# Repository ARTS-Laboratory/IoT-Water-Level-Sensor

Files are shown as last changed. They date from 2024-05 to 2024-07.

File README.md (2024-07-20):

# IoT Water Level Sensor

This is a water height sensor developed by the ARTS-Lab at the University of South Carolina in conjunction with the South Carolina Department of Environmental Services (SC DES) Dam Safety Program. The purpose of this sensor is to provide a low-cost, open-source alternative to traditional gaging equipment. 

<p align="center">

</p>
<p align="center">
Sensor deployed above inlet to Lake Wallace in Bennetsville, SC.
</p>

<p align="center">
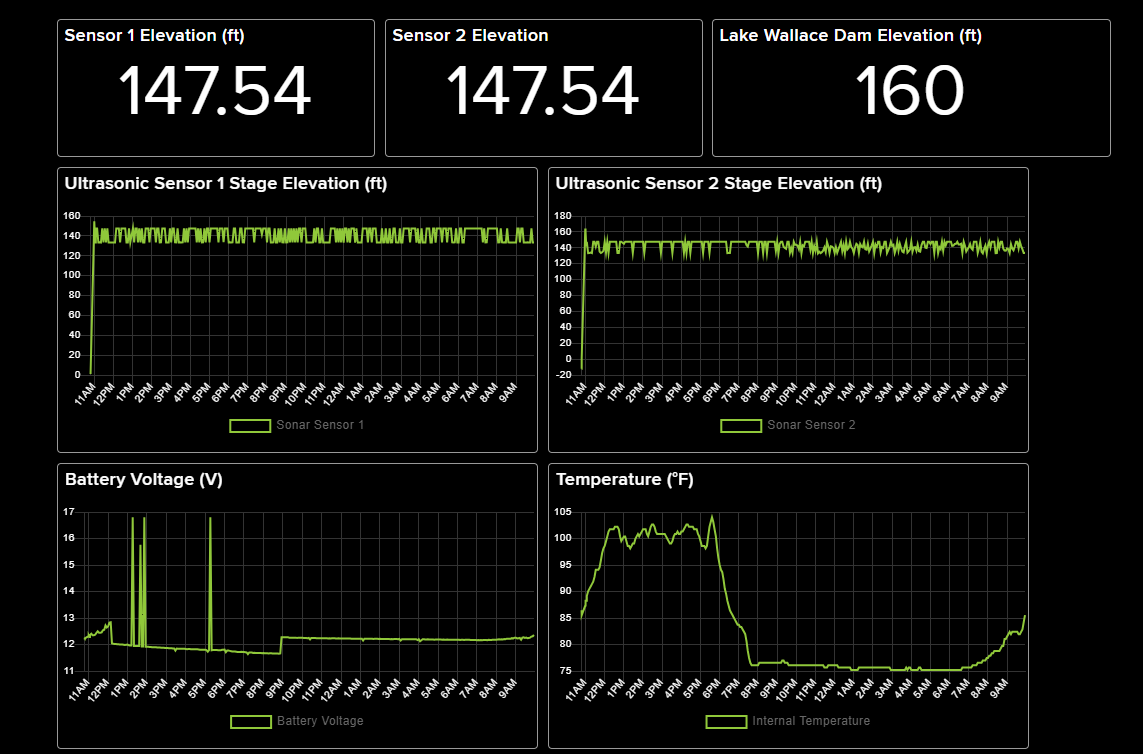
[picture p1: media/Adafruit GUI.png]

</p>
<p align="center">
The online GUI using Adafruit that displays water elevation in real time.
</p>

## Features
### Water Elevation Measurement
The sensor package uses two ultrasonic sensors to measurement the height of water in a reservoir, lake, or pond. These sensors are low cost, but are accurate to +/- 1 inch within a range of 18 ft.
<p align="center">

</p>
<p align="center">
The low cost, JSN-SR04T ultrasonic sensor used with Arduinos.
</p>

### Internet Connectivity
Our package can connect to the Adafruit online server. A free account can be made with them to host data online, and a small subscription fee can upgrade the service for more data storage.
</p>
This device can connect to Internet via cellular or Wifi.
<p align="left">

<align="right">

</p>
On the left, the SIM7000 cellular shield. On the right, the WINC1500 Wifi shield.
</p>

### Long Term Data Storage
Because the online server only saves data for 60 days, to ensure that all data is recorded for future use, we use an SD card and Real Time clock with this sensor package to save all data with a timestamp in a .CSV format. 

## System Development
Contains the hardware and software developed for the project. Use this folder to create and troubleshoot a sensor.

## Licensing and Citation

This work is licensed under a Creative Commons Attribution-ShareAlike 4.0 International License [cc-by-sa 4.0].



Cite this as: 

@Misc{ARTSLabIotWaterLevel,    
  author = {ARTS-Lab},  
  howpublished = {GitHub},  
  title  = {IoT Water Level Sensor},   
  groups = {ARTS-Lab},    
  url    = {https://github.com/ARTS-Laboratory/IoT-Water-Level-Sensor},   
}

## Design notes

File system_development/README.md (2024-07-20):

# Systems Variations  
The IOT water height sensor comes in two main categories: Cellular and Wifi.
<p>
Select whichever method you would like to use to connect your water height sensor to the Internet. Each varation comes with the complete files needed to find parts, assemble the package, and program the Arduino.
</p>

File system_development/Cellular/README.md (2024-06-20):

# Celluar Versions

## v0.1
Legacy version (2022 - 2023) 

## v0.2
Current version (2024 - )

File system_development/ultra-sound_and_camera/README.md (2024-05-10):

# Ultra-sound and Camera

v0.1
* list items that make this version special
* list items that make this version special
* list items that make this version special

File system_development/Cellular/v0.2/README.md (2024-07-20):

# Celluar V0.2

### Arduino Code
This folder contains all of the Arduino code used in this sensor project, including special custom formatted libraries that you will have to install in order to make the Arduino code work properly on your hardware.

### Custom PCB's
This folder contains the KiCad files used to create the custom data logging PCB and power management PCB.

### Parts List
A detailed parts list with part numbers and ordering information. This list gives the location and price of where we ordered every part to assemble both the package and the individual PCB's.
The parts used in the PCB's have their identification number from the schematics included so that you will be able to see where each part goes when assembling the PCB's.

# Important Information:

### Botletics SIM7000 Shield

This sensor package uses a Botletics SIM7000 shield to connect to the Internet over the cellular network.
The wiki for this board is found [here](https://www.botletics.com/products/sim7000-shield) for more information.
Here is a tutorial for how to set up and use the board: [Instructables](https://www.instructables.com/LTE-NB-IoT-Shield-for-Arduino/) *Note that we do not use a separate 3.7V battery to power our sensor package.

### Hologram SIM card

To connect to the Internet over the cell network, you will need to have a SIM card. You can buy a SIM card from [Hologram](https://www.hologram.io/).
You will need to register with Hologram, purchase a SIM card and a data plan, and then work with your SIM card over the Hologram site.
Our SIM card is this [IOT card](https://store.hologram.io/products/single-core-global-euicc-iot-sim-card). 

### Adafruit IO

We use the Adafruit IO server to monitor our sensor package over the Internet in real time. You will need to create an account with Adafruit, however it is free.
To learn how to sign up for the Adafruit IO server, use this [tutorial](https://learn.adafruit.com/welcome-to-adafruit-io).
You will also need to learn how to use [feeds](https://learn.adafruit.com/adafruit-io-basics-feeds) and [dashboards](https://learn.adafruit.com/adafruit-io-basics-dashboards).

### PCB's

To use this sensor, you will have to assemble custom PCB's. The PCB's were designed using the [KiCad](https://www.kicad.org/) software, a free-to-use PCB editor. All the schematics can be found in the Datalogging and Power PCB folders under the file name .kicad_sch. The provided parts list references the .kicad_sch files so that you can know how to assemble the PCB on your own. Datasheets for each part can also be found within the .kicad_sch file.
We have ordered PCB's from [OSH Park](https://oshpark.com/) and have liked the results. Simply drag and drop the .kicad_pcb file from the PCB folder into OSH Park to create a PCB!

# Assembly Instructions

### Assemble PCB's

The first step is acquire PCB and solder the components. Refer to the .kicad_sch and .kicad_pcb files in the respective folders for the placement of each component. 
Their locations have been labeled on the PCB's for greater ease.

(Include pictures of before and after)

### Fit Boards

The next step is to put together the Arduino Mega, Botletics SIM7000 shield, and the completed PCB's as shown:

(Include pictures)

### Formatting the Code

To get the CellularCodev0.2 to work with your particular Adafruit account, we will have to format the code a little.

First acquire your username and key from the Adafruit IO website:

<p align="center">
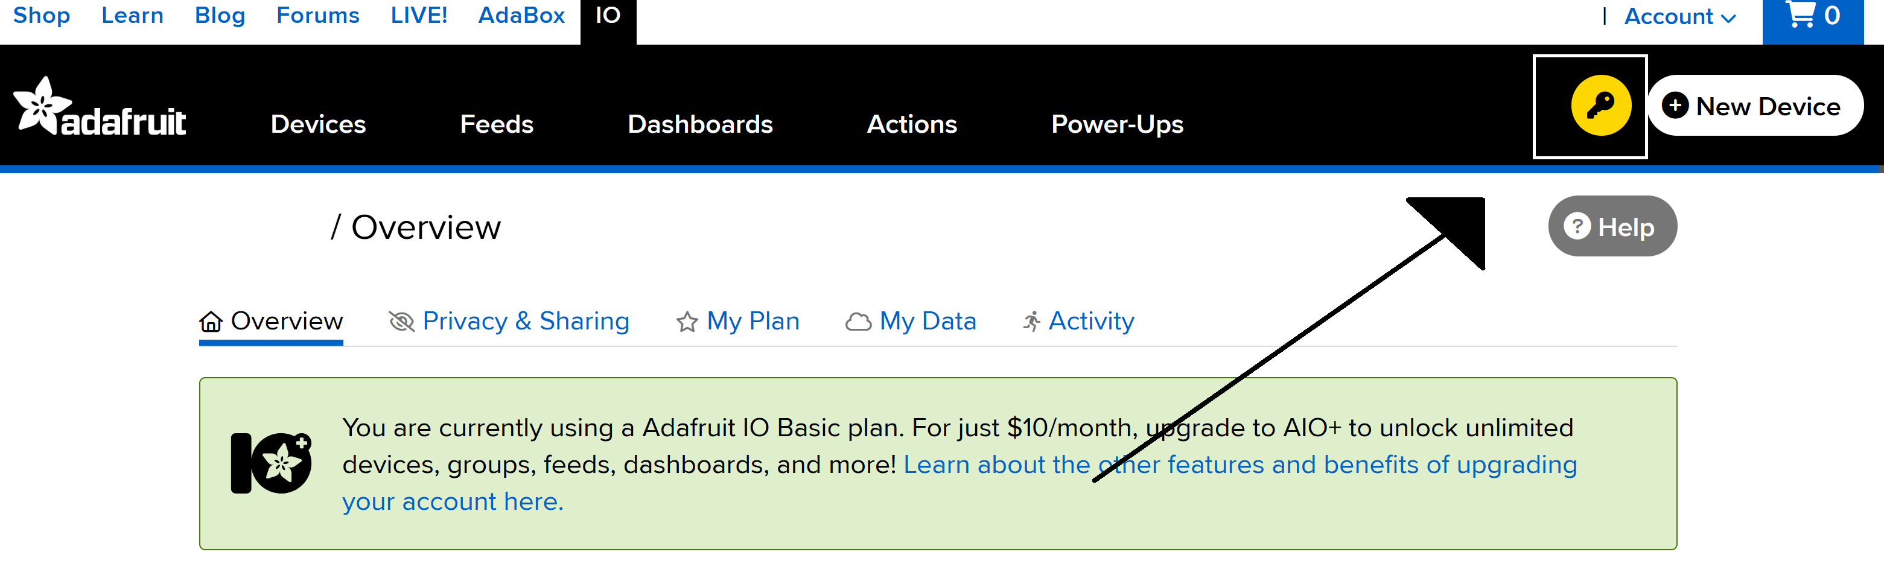
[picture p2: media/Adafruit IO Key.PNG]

</p>

Using your Adafruit username and key, fill in this line in the code:

<p align="center">
<img src="https://github.com/ARTS-Laboratory/IoT-Water-Level-Sensor/blob/main/media/Adafruit%20Arduino%20Key%20Location.PNG" alt="drawing" width=600"/>
</p>

Power your device, turn it on, and start transmitting! All relevant schematics are provided for the PCB's, and the Arduino code is annotated with explanations. Feel free to dig into both to tweak the device to your desire.

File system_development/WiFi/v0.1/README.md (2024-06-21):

# Wifi V0.1

## WifiCode_v0.1
This folder contains all of the Arduino code used in this sensor project.

## Data Collection - Logging PCB
This folder contains the KiCad files used to create the custom data logging PCB

## Power PCB
This folder contains the KiCad files used to create the custom Power supply and monitoring PCB

## Parts List
A detailed parts list with part numbers and ordering information can be found in the Wifi Water Height Sensor
Package Parts List.

# Important Information:

### WINC1500 Shield

This sensor package uses a WINC1500 shield to connect to the Internet over Wifi.
It is produced by Adafruit Industries. Here is a [tutorial](https://learn.adafruit.com/adafruit-winc1500-wifi-shield-for-arduino) by them for how to set up and use the board.
The WINC1500 has an SD card module on it.

### Adafruit IO

We use the Adafruit IO server to monitor our sensor package over the Internet in real time. You will need to create an account with Adafruit, however it is free.
To learn how to sign up for the Adafruit IO server, use this [tutorial](https://learn.adafruit.com/welcome-to-adafruit-io).
You will also need to learn how to use [feeds](https://learn.adafruit.com/adafruit-io-basics-feeds) and [dashboards](https://learn.adafruit.com/adafruit-io-basics-dashboards).

### PCB's

To use this sensor, you will have to assemble custom PCB's. All the schematics can be found in the Datalogging and Power PCB folders and parts list. 
We have ordered PCB's from [OSH Park](https://oshpark.com/) and have liked the results. Simply drag and drop the .kicad_pcb file from the PCB folder into OSH Park to create a PCB!

# Assembly Instructions

### Assemble PCB's

The first step is acquire PCB and solder the components. Refer to the .kicad_sch and .kicad_pcb files in the respective folders for the placement of each component. 
Their locations have been labeled on the PCB's for greater ease.

(Include pictures of before and after)

### Fit Boards

The next step is to put together the Arduino Mega, WINC1500 shield, and the completed PCB's as shown:

(Include pictures)

### Formatting the Code

To get the WifiCode_v0.1 to work with your particular Adafruit account, we will have to format the code a little.

First acquire your username and key from the Adafruit IO website:

<p align="center">

</p>

Using your Wifi Network name and password, fill in these lines in the code:

<p align="center">
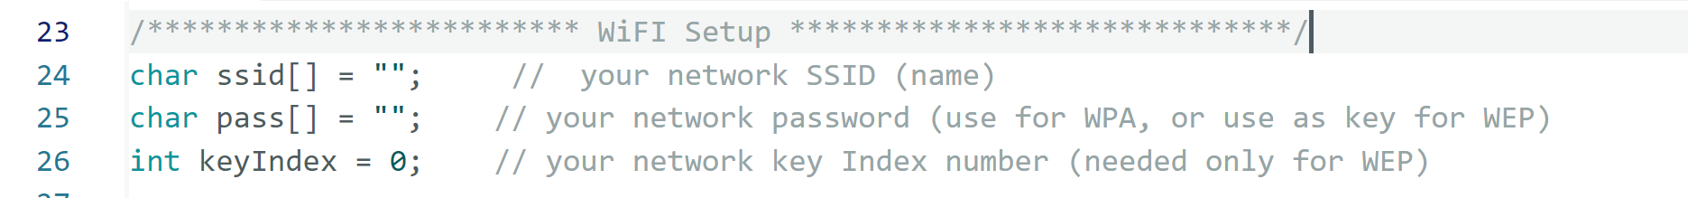
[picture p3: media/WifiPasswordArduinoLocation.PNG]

</p>

Power your device, turn it on, and start transmitting! All relevant schematics are provided for the PCB's, and the Arduino code is annotated with explanations. Feel free to dig into both to tweak the device to your desire.

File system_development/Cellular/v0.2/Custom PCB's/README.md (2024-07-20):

# PCB Files
The cellular board requires two custom PCB's, one for power management and one for data collection. Both are designed and edited using the Kicad software.

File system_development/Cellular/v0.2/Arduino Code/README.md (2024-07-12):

# Arduino Code

## Sensor Code
The INO file is the Arduino code which can be uploaded to an Arduino Mega. Remember to include
the Adafruit user name and AIO key so that it will connect to the right server.

## Special Libraries
The code will not work without special Arduino libraries that have been altered 
and need to manually installed in the "Arduino libraries" folder, overwriting the existing libraries if they
were already installed. All files are tested and are mutually compatible. We have found compatibility
issues with other versions of these libraries, so it is important that all are manually installed
in the Arduino libraries folder.

## Auxillary Code
This contains three helpful Arduino codes. One sets the time on an RTC in order to calibrate it. 
The other is a demo code which can also be found in the Botletics folder in the Special Arduino Libraries folder.
The LTE Demo is useful to troubleshoot connectivity issues with the SIM card. The last is an I2C address finder which
can be used to find the I2C address of the INA219 current measuring chip.

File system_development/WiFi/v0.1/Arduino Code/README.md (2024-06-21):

# Arduino Code

### Sensor Code

The INO file is the Arduino code which can be uploaded to an Arduino Mega. Remember to include
the Adafruit user name and AIO key so that it will connect to the right server.

The libraries used with the Wifi sensor package are standard and can be downloaded unto your computer using the 
Arduino software

### Auxillary Code

This contains two helpful Arduino codes, one to the set the time on an RTC in order to calibrate it. 
The other is a demo code which can also be found in the Wifi101 folder in the Examples tab in the Arduino software
after the Wifi101 library has been installed. This will help to troubleshoot connectivity issues.

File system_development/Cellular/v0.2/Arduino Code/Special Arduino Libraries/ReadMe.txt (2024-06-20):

# Special Libraries

## Adafruit_FONA / Adafruit_MQTT_Library / BotleticsSIM7000
The libraries for the cellular model are hodge-podge and subject to problems. The original Adafruit Fona library has to be overwritten
by the special Botletics Adafruit Fona Library that connects code for use with LTE. The Sim7000 works off of LTE data
and the original Adafruit Fona Library does not contain LTE connection code. Also, the line "#define SSL_FONA 1" in the
.h code in the Fona Library needs to be changed to "#define SSL_FONA 0" for the code to work. Copies of working Arduino libraries are contained
in this folder in case an automatic update changes the Arduino libraries and prevents the module from working.

## All Others
The other libraries are more standard and are included only for convenience. They are needed to use some of the hardware included in the sensor package. They can be installed from the Arduino software
and are included here if you would like to manually install them.

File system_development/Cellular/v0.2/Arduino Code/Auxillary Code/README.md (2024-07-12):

# Auxillary Code

## LTE_Demo
This was developed by Botletics and can be used with the Botletics board to diagnose connectivity issues with the Botletics shield or SIM card

## RTC_Set_Time
This code sets the Real Time Clock to the current time.

##I2C Address Finder
Gives the I2C address of the INA219 chip, usually 0x4X, which can change depending on the type of chip used.
The right I2C address has to be programmed in the Cellular Code for the INA219 chip to work correctly.

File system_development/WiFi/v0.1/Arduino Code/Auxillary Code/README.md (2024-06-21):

# Auxillary Code

### Connect with WPa

This is used with the Wifi shield to test a Wifi connect with WPA (typical) credentials. Use it to see
whether you Wifi connection and signal strength is good enough to transmit data.

### RTC_Set_Time

This code sets the Real Time Clock to the current time.

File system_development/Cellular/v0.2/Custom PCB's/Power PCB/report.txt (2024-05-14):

Plotted to 'C:\Users\User\Documents\GitHub\IoT-Water-Level-Sensor\system_development\Cellular\v0.2\Power PCB\Power PCB-F_Cu.gbr'.
Plotted to 'C:\Users\User\Documents\GitHub\IoT-Water-Level-Sensor\system_development\Cellular\v0.2\Power PCB\Power PCB-B_Cu.gbr'.
Plotted to 'C:\Users\User\Documents\GitHub\IoT-Water-Level-Sensor\system_development\Cellular\v0.2\Power PCB\Power PCB-F_Paste.gbr'.
Plotted to 'C:\Users\User\Documents\GitHub\IoT-Water-Level-Sensor\system_development\Cellular\v0.2\Power PCB\Power PCB-B_Paste.gbr'.
Plotted to 'C:\Users\User\Documents\GitHub\IoT-Water-Level-Sensor\system_development\Cellular\v0.2\Power PCB\Power PCB-F_Silkscreen.gbr'.
Plotted to 'C:\Users\User\Documents\GitHub\IoT-Water-Level-Sensor\system_development\Cellular\v0.2\Power PCB\Power PCB-B_Silkscreen.gbr'.
Plotted to 'C:\Users\User\Documents\GitHub\IoT-Water-Level-Sensor\system_development\Cellular\v0.2\Power PCB\Power PCB-F_Mask.gbr'.
Plotted to 'C:\Users\User\Documents\GitHub\IoT-Water-Level-Sensor\system_development\Cellular\v0.2\Power PCB\Power PCB-B_Mask.gbr'.
Plotted to 'C:\Users\User\Documents\GitHub\IoT-Water-Level-Sensor\system_development\Cellular\v0.2\Power PCB\Power PCB-Edge_Cuts.gbr'.
Created Gerber job file 'C:\Users\User\Documents\GitHub\IoT-Water-Level-Sensor\system_development\Cellular\v0.2\Power PCB\Power PCB-job.gbrjob'.
Info: Done.

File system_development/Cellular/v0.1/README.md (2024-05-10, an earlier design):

# Cellular v0.1

This is an Arduino Mega-based stage sensor developed by interns at the South Carolina Department of Health and Environmental Control (SC DHEC) Dam Safety Program. The purpose of this sensor is to provide a low-cost, open-source alternative to traditional gaging equipment. Both an ultrasonic sensor and a pressure transducer are used to measure the stage, and all data is sent via the Hologram cellular network to a graphic user interface (GUI) hosted on Adafruit IO. *Note: this repository was formerly named "DHEC-Stage-Sensor".

<p align="center">
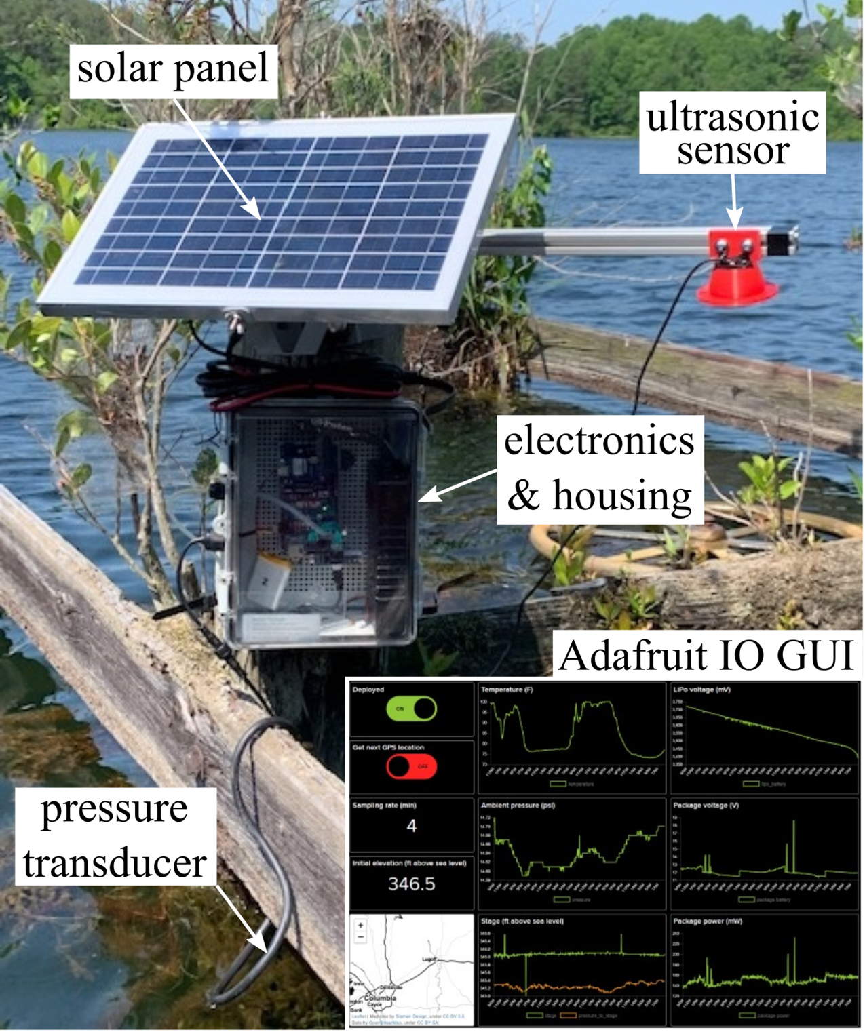
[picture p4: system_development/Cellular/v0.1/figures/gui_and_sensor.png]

</p>
<p align="center">
Figure 1: Sensor deployed on the primary spillway of a dam transmitting data to the GUI.
</p>

## characteristic data
contains validation data for the sensor, as well as test data for filtering, pressure transducer calibration

## code
contains all the Arduino codes for the sensor

## EDA
contains all electronic design automation (EDA) files for the custom data logging and power PCBs

## field tests
contains data for all field tests performed with the sensor package, as well as Python scripts for visualizing data

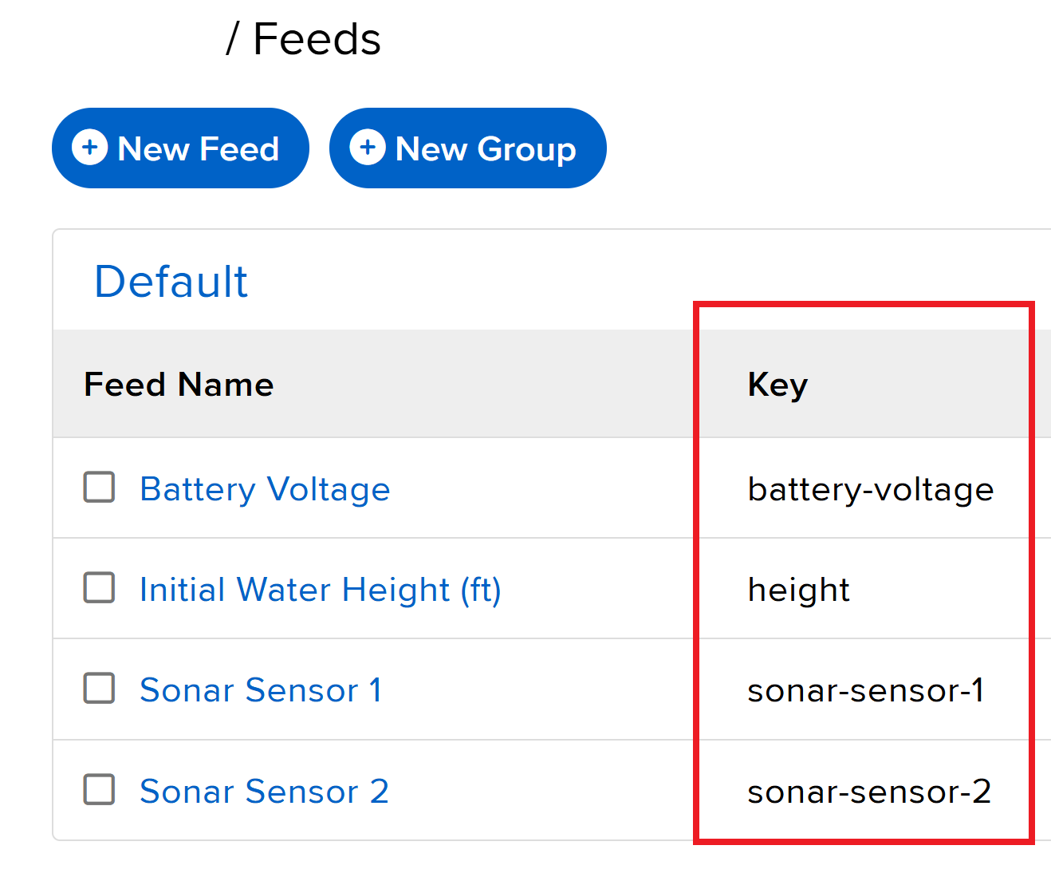
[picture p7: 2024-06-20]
media/Adafruit IO Feed Names.PNG

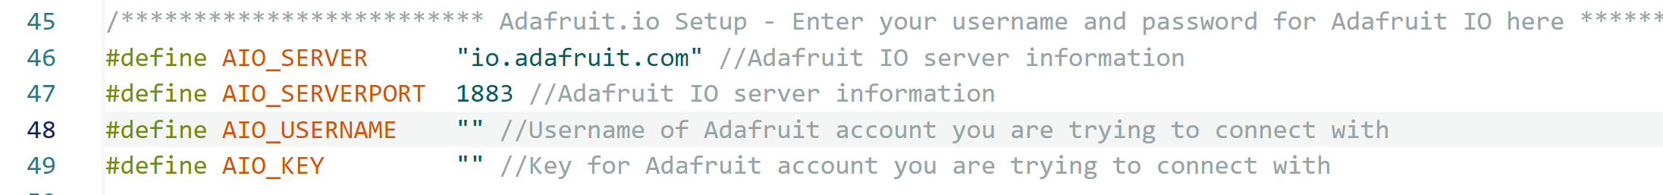
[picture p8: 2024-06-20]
media/Adafruit Arduino Key Location.PNG

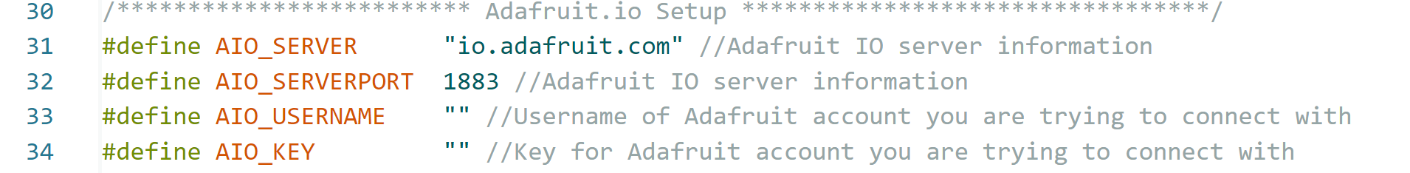
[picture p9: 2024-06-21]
media/WifiArduinoKey Location.PNG

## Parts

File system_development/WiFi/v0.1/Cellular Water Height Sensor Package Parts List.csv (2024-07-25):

Material Ordering List
Part Name
Power Board PCBv0.2 | Manufacturer Part # | Digikey Part # | Supplier | Code on Schematic | Price per unit (5/14/2024)
Barrell Jack | PJ-102B | CP-102B-ND | CUI Devices | J1 | $0.65
Slide Switch | AS11AP | 360-3719-ND | NKK Switches | SW1 | $4.07
Diode SMD | DDZ16-7 | 31-DDZ16-7TR-ND | Diodes Incorporated | D1 | $0.25
Resistor SMD | RL1206FR-070R1L | 311-0.1LWTR-ND | YAGEO | R1 | $0.43
Capacitor SMD | KGM31BR71H104KT | 478-KGM31BR71H104KTTR-ND | KYOCERA AVX | C1 / C2 | $0.18
Current Measuring Chip | INA219AIDR | 296-23978-2-ND | Texas Instruments | U2 | $2.16
Resistor SMD | RC1206FR-074K7L | 311-4.70KFRTR-ND | YAGEO | R3 / R4 | $0.10
5V Linear Regulator | LF50CDT-TR | 497-1534-2-ND | STMicroelectronics | U1 | $0.99
Power Board PCB | Custom | Custom | OSH Park | N/A
Datalogging Boardv0.21 | Manufacturer Part # | Digikey Part # | Supplier | Code on Schematic
3.3 V Linear Regulator | UA78M33IKVURG3 | 296-41035-2-ND | Texas Instruments | U1 | $0.83
Capacitor SMD | CL31B104KBCNNNC | 1276-1017-2-ND | Samsung Electro-Mechanics | C1 | $0.11
Capacitor SMD | CL31B334KBFNNNE | 1276-1138-2-ND | Samsung Electro-Mechanics | C2 | $0.13
SD Module | B0B5H3421M | ASIN (Amazon) | AOICRIE | Micro_SD1 | $4.99 (for 12)
Real Time Clock Module | B09KPC8JZQ | ASIN (Amazon) | AITRIP | RT1 | $7.99 (for 3)
Ultrasonic Sensor (JSN-sr04t v3.0) | B0C73XZRFQ | ASIN (Amazon) | Shutao | US1 / US2 | $21.99 (for 5)
Datalogging Board PCB | Custom | Custom | OSH Park | N/A
Separate Electronics and Parts | Manufacturer Part # | Supplier | Distributer #
Arduino Mega | Arduino Mega 2560 Rev3 | Elegoo |  |  | $19.99
Wifi Shield (WINC1500) | 3654 | Adafruit |  |  | $24.95
Battery (12 V) | YB12011000-USB | TalentCell | Amazon ASIN B016BJCRUO |  | $61.99
Wires (M/F) | Multicolored Dupont Wire | Elegoo |  |  | $6.59
Pins and Headers (M/F) | 8541770554 | Glarks | Amazon ASIN B07CWSXY7P |  | $12.98
MicroSD Card | AF8GUD3-WAAXX | ATP Electronics, Inc. | Digikey #1282-AF8GUD3-WAAXX-ND |  | $3.61
Frame / Box Parts | Manufacturer Part # | Supplier | Amazon ASIN | Size
Waterproof Electronics Box | B0B87V7QTH | TICONN | B0B87V7QTH | 4.3 x 6.7 x 8.7" | $26.96
Cable Glands | B4190 | Tuparka | B0BLYSTRL5 |  | $13.89
Solar Panel 30W | BC-30W-ZM | Suner Power |  |  | $69.95
SAE to Barrel Jack Wire | SAEPCSP-1 | E-Outstanding | B08JG9XW3C |  | $7.99

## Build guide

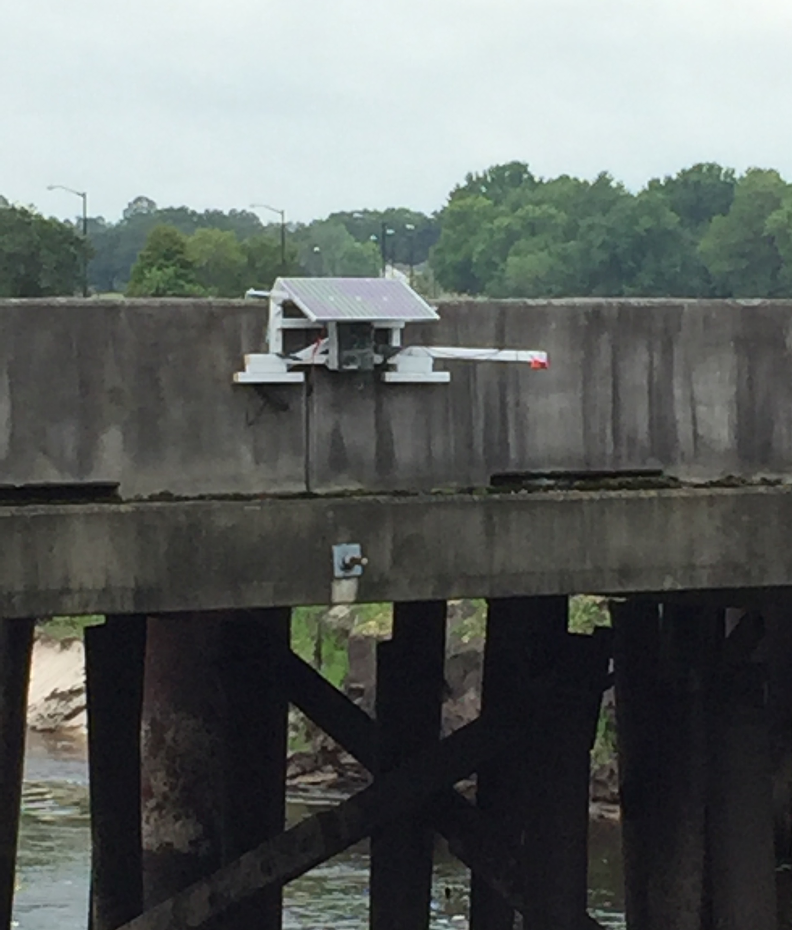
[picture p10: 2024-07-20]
media/Lake Wallace Installation 3.png

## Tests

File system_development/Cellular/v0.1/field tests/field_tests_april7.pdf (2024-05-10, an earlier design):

# Field Tests

### Corinne Smith

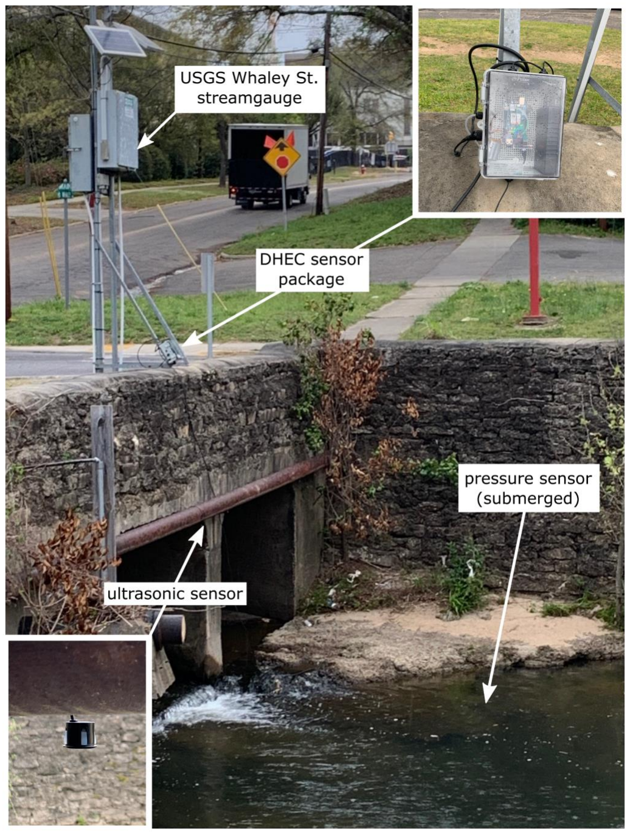
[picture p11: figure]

3/31

- Fixed on USGS Whaley St streamgage
- Ultrasonic sensor was fixed to the pipe, pressure sensor was not fixed
- Caused problems to pressure sensor when the flow rate picked up
- Solution: deploy pressure sensor to the side of the main flow
- Data session: 9:00 – 18:32
- Cause of failure: network would not reconnect, so Adafruit IO was completely unresponsive
- Possibly encountered a Network Denied status
- Ultrasonic had noisy readings between major rainfall periods
- Possible something was stuck under the sensor that gave false readings

## Results

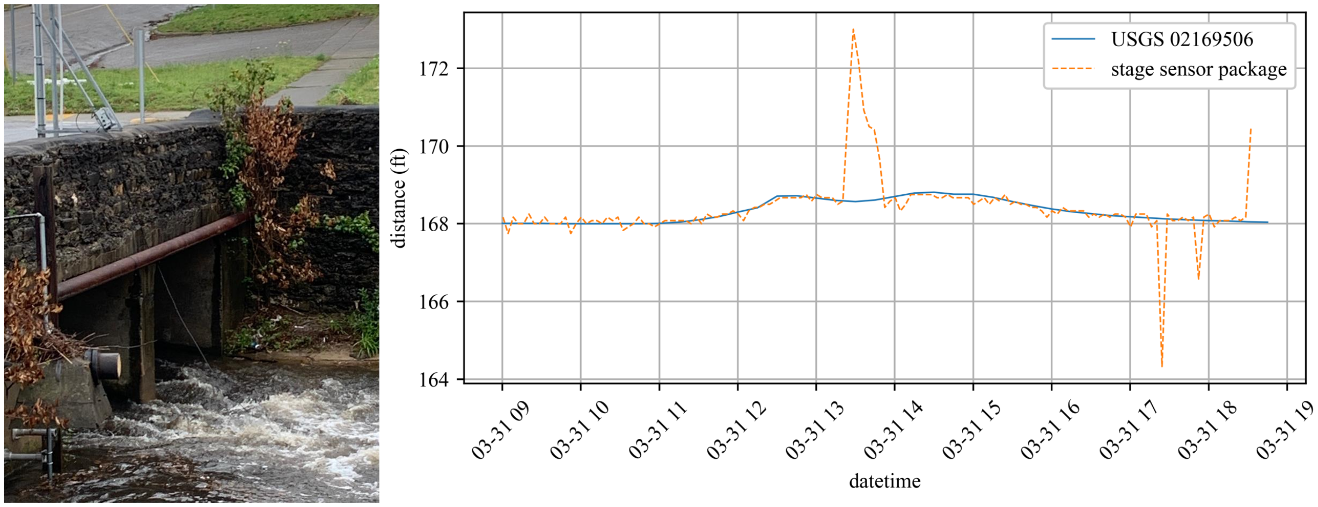
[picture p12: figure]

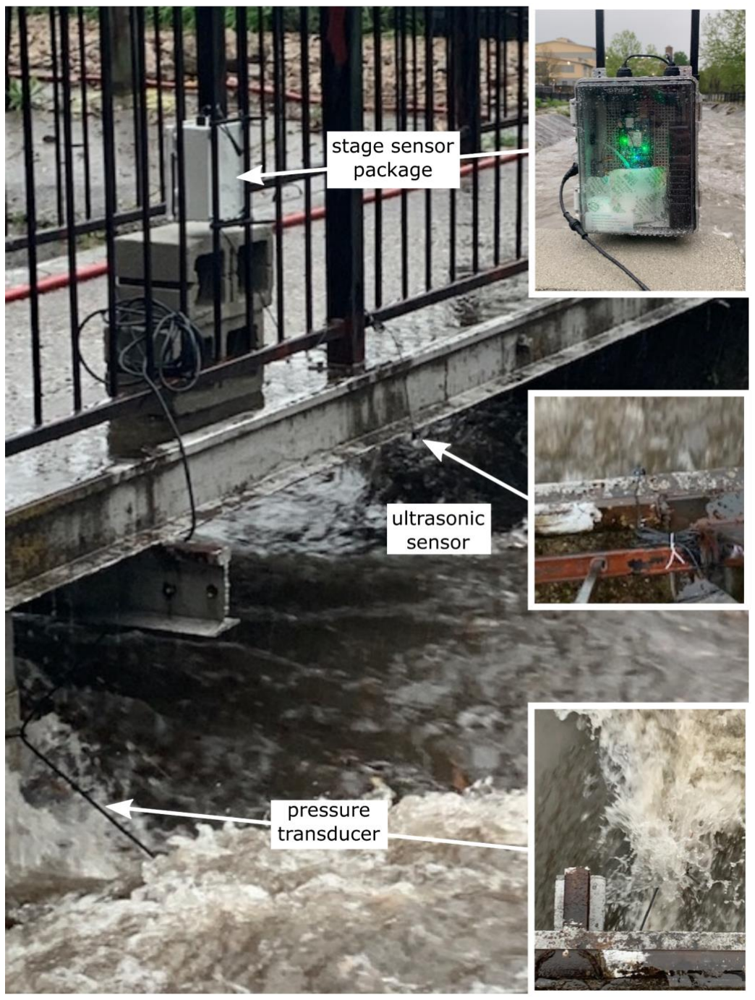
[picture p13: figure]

4/5

- Severe thunderstorms and tornado warning
- Deployed behind 300 Main on bridge
- Channel profile differs from USGS; peaks should line up, but magnitude may not
- Pressure sensor was secured to bridge leg, ultrasonic sensor was draped over side
- Data collection timeframe: 13:50 – 20:42
- Cause of failure: waterproofing issues shorted datalogging board
- Solution: add glue to further waterproof area around cable glands
- Some noisy readings on ultrasonic sensor towards end of deployment
- Possible cause: sensor may not be as “waterproof” as datasheet claims

## Results

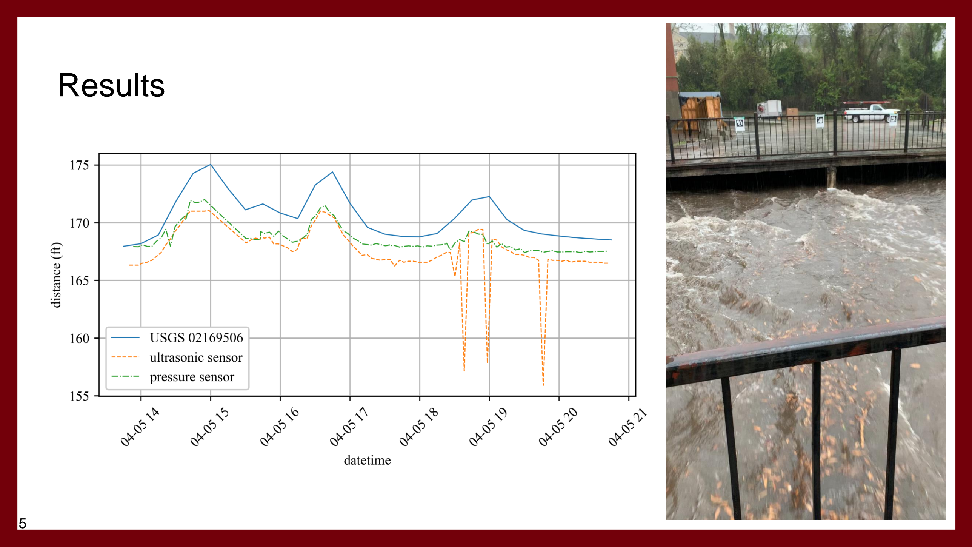
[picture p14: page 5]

4/6-4/7

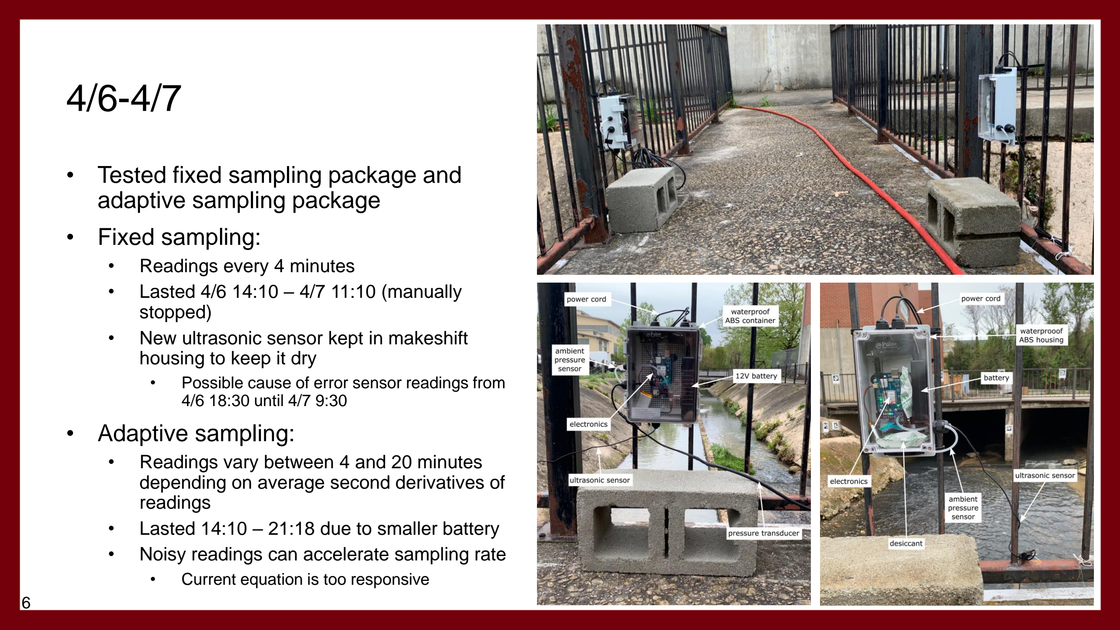
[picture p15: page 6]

- Tested fixed sampling package and adaptive sampling package
- Fixed sampling:
- Readings every 4 minutes
- Lasted 4/6 14:10 – 4/7 11:10 (manually stopped)
- New ultrasonic sensor kept in makeshift housing to keep it dry
- Possible cause of error sensor readings from 4/6 18:30 until 4/7 9:30
- Adaptive sampling:
- Readings vary between 4 and 20 minutes depending on average second derivatives of readings
- Lasted 14:10 – 21:18 due to smaller battery
- Noisy readings can accelerate sampling rate
- Current equation is too responsive

## Results

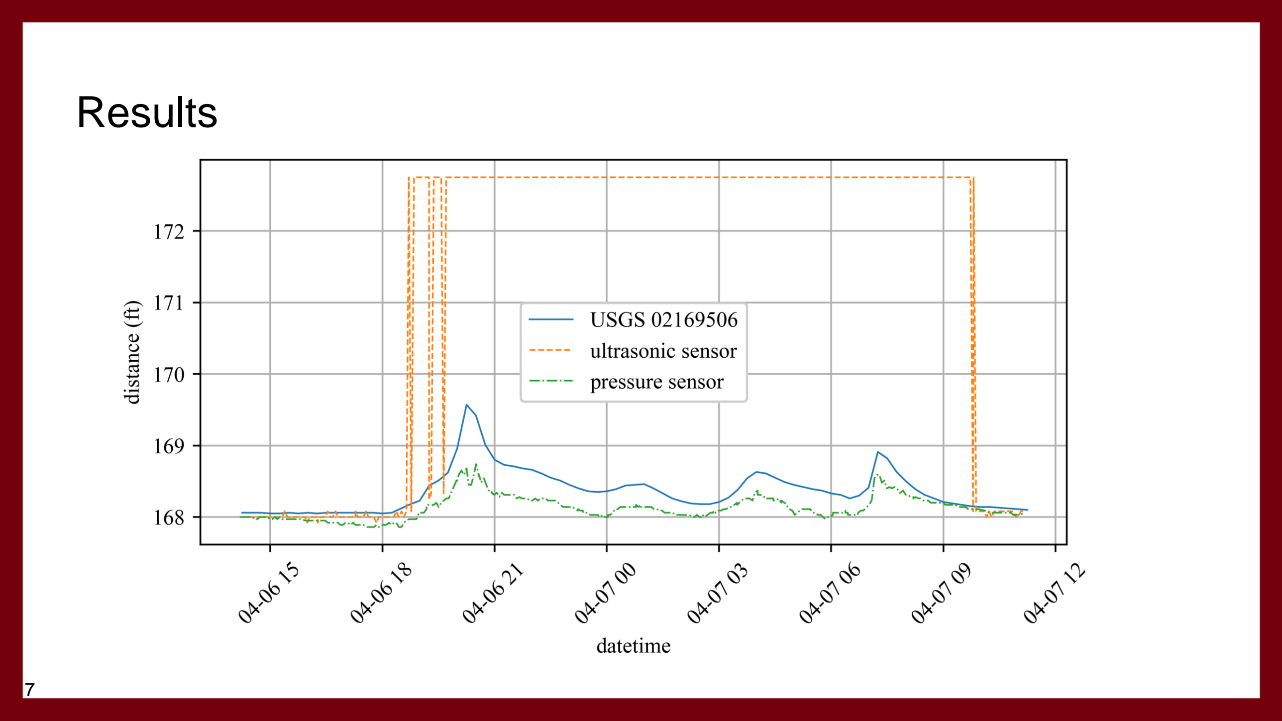
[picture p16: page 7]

## Results

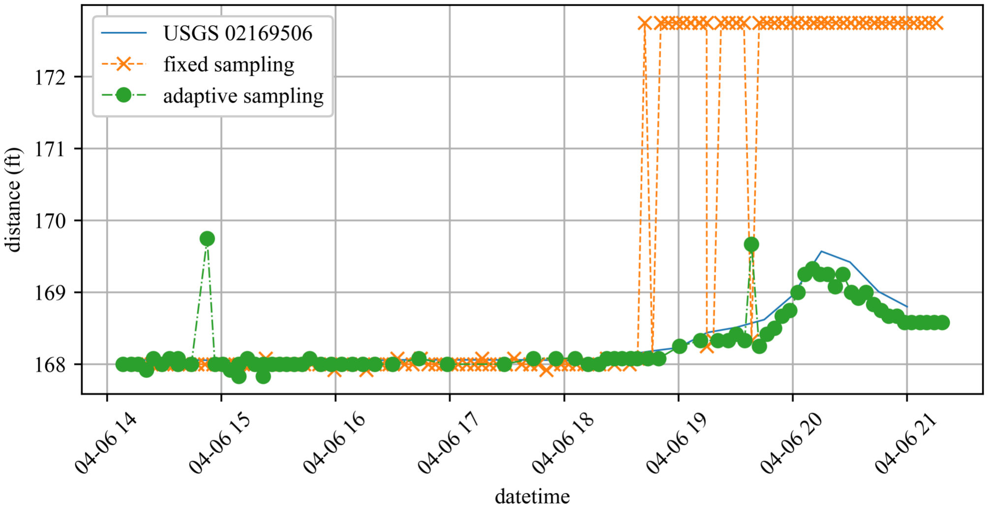
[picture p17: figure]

## Improvements

- Switch to a two-transducer ultrasonic sensor
- Two transducers reduces angle spread, which increases accuracy by reducing area that sensor is capturing
- Average multiple sensor readings to reduce outliers
- Design waterproofing housing for sensor
- Make a less responsive time equation (and test more with adaptive sampling package)
- Secure pressure transducer and ultrasonic sensor to structure better
- Implement a trigger that notifies if readings haven’t been taken after a certain timeframe

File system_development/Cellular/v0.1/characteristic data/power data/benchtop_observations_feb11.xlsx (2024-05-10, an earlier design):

Event | Current | Time
11.1V on barrel
Net connection | 100
MQTT connection | 110
Subscription waiting | 110
Data collection | 120
Sleep | 50-60
GPS on | 120
Sleep after GPS was on | 60
Data after GPS was on | 120
5v on VIN
before net | 60
net to mqtt | 60
mqtt to subscribe loop | 60
data collection | 70
sleep | 30
gps | 70
sleep after gps | 40
data after gps | 70
 | 5V pin reads 3.8V, too close to reg limits
7.4V on VIN
before net | 100-90
net to mqtt | 100
mqtt to subscribe loop | 110
data collection | 120-110
sleep | 50
gps | 120
sleep after gps | 60
data after gps | 120
 | 5V pin reads 4.96V, checks out
7.4V on barrel jack
before net | 100-90
net to mqtt | 100
mqtt to subscribe loop | 100-110
data collection | 110-120
sleep | 50
gps | 120
sleep after gps | 60
data after gps | 120 | no clear change in wattage after GPS has been turned on either, may just need to find an AT command to turn it back off
12V on barrel jack try 2
before net | 100-90
net to mqtt | 100
mqtt to subscribe loop | 110
data collection | 120-110
sleep | 50
gps | 120
sleep after gps | 60
data after gps | 120
 | 5V pin reads 4.96V, same as with 7.4V
12V on barrel jack SPD1168X
before net | 0.97 | 22.39
net to mqtt | 0.102 | 22.42
mqtt to subscribe loop | 0.11 | variable
data collection | 0.121-0.113 | 8
sleep | 0.053 | 20 (set by user)
gps | 0.121 | 21.35 (unsuccessful)
sleep after gps | 0.62 | 20 (set by user) | (Only caused by LED! Without led 0.53)
data after gps | 0.121 | 8 | (Only caused by LED! Without led 0.113)
12V on barrel jack SPD1168X no sleep
before net | 0.94
net to mqtt | 0.102
mqtt to subscribe loop | 0.11
data collection | 0.122 - 0.112
sleep | 0.1
gps | 0.12
sleep after gps | 0.109
data after gps | 0.119
12V on barrel jack SPD1168X no sleep |  |  | mAH
before net | 94 | 22 | 0.5744444444
net to mqtt | 102 | 22 | 0.6233333333
mqtt to subscribe loop | 110 | 20 | 0.6111111111
data collection (1) | 122 | 1 | 0.03388888889
data collection (2) | 112 | 7 | 0.2177777778
sleep | 53 | 292 | 4.298888889
gps | 120 | 21.35 | 0.7116666667
initialization consumption: |  | 1.808888889
regular cycle consumption: |  | 4.550555556 |  | duration with sleep: | 2.289
cycle with GPS consumption: |  | 5.262222222 |  | duration no sleep: | 1.246

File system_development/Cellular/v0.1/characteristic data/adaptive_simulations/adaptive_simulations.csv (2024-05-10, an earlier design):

true signal | adaptive | adaptive_2 | adaptive_3_index | adaptive_3 | adaptive_4_index | adaptive_4 | adaptive_5_index | adaptive_5 | adaptive_6_index | adaptive_6 |  | adaptive_7_index | adaptive_7
166.75 | 166.75 | 166.75 | 5 | 166.75 | 5 | 166.75 | 5 | 166.75 | 5 | 166.756 |  | 5 | 166.756
167.08 | 167.08 | 167.08 | 6 | 167.08 | 6 | 167.08 | 6 | 167.08 | 6 | 167.08 | 0.07 | 6 | 167.08 | 0.07
167.42 | 167.42 | 167.42 | 7 | 167.42 | 7 | 167.42 | 7 | 167.42 | 10 | 169.25 | 0.5 | 10 | 169.25 | 0.5
168.08 |  |  | 11 | 169.75 | 9 | 168.58 | 11 | 169.75 | 11 | 169.75 | 0.6 | 11 | 169.75 | 0.6
168.58 |  |  | 14 | 171 | 10 | 169.25 | 12 | 170.33 | 12 | 170.33 | 0.72 | 12 | 170.33 | 0.72
169.25 | 169.75 | 169.75 | 15 | 171 | 11 | 169.75 | 13 | 170.58 | 13 | 170.58 | 0.77 | 13 | 170.58 | 0.77
169.75 |  |  | 16 | 171 | 12 | 170.33 | 14 | 171 | 14 | 171 | 0.78 | 14 | 171 | 0.78
170.33 |  |  | 17 | 171 | 13 | 170.58 | 15 | 171 | 15 | 171 | 0.35 | 15 | 171 | 0.35
170.58 |  |  | 18 | 171.08 | 14 | 171 | 16 | 171 | 17 | 171 | 0.25 | 17 | 171 | 0.25
171 | 171 | 171 | 20 | 168.5 | 15 | 171 | 17 | 171 | 20 | 168.5 | 0.63 | 21 | 168.67 | 0.6
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

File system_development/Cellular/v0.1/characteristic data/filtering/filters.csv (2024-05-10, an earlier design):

true signal | kalman | moving average | median | last replacement
166.75 |  | 166.5 | 166.75 | 166.75
167.08 |  | 166.65 | 167.08 | 167.08
167.42 | 158.65 | 166.87 | 167.42 | 167.42
168.08 | 162.33 | 167.18 | 168.08 | 168.08
168.58 | 164.77 | 167.58 | 168.58 | 168.58
169.25 | 166.52 | 168.08 | 169.25 | 169.25
169.75 | 167.78 | 168.62 | 169.75 | 169.75
170.33 | 168.78 | 169.2 | 170.33 | 170.33
170.58 | 169.48 | 169.7 | 170.58 | 170.58
171 | 170.07 | 170.18 | 171 | 171
171 | 170.44 | 170.53 | 171 | 171
171 | 170.66 | 170.78 | 171 | 171
171 | 170.79 | 170.92 | 171 | 171
171.08 | 170.9 | 171.02 | 171.08 | 171.08
168.25 | 169.87 | 170.47 | 168.25 | 168.25
168.5 | 169.33 | 169.97 | 168.5 | 168.5
168.67 | 169.07 | 169.5 | 168.67 | 168.67
168.58 | 168.88 | 169.02 | 168.58 | 168.58
168.75 | 168.83 | 168.55 | 168.75 | 168.75
168.67 | 168.77 | 168.63 | 168.67 | 168.67
168.75 | 168.76 | 168.68 | 168.75 | 168.75
168.17 | 168.53 | 168.58 | 168.17 | 168.17
168.17 | 168.39 | 168.5 | 168.17 | 168.17
168 | 168.24 | 168.35 | 168 | 168
167.83 | 168.08 | 168.18 | 167.83 | 167.83
167.5 | 167.85 | 167.93 | 167.5 | 167.5
167.67 | 167.78 | 167.83 | 167.67 | 167.67
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

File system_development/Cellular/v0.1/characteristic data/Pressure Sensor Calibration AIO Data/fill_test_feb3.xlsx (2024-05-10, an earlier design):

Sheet: unprocessed data
2022-02-03 | 10:59:27 | 105 | 0.51 | 0.29 | 0.67 | 0.03 | 0.08 | -0.17 | Test Feb 3
2022-02-03 | 10:59:30 | 105 | 0.51 | 0.29 | 0.67 | 0.03 | 0.08 | -0.17 | Temperature: 68
2022-02-03 | 10:59:32 | 105 | 0.51 | 0.29 | 0.67 | 0.03 | 0.08 | -0.17 | Pressure atm: 30.18 in
2022-02-03 | 10:59:34 | 106 | 0.52 | 0.3 | 0.7 | 0.05 | 0.1 | -0.14
2022-02-03 | 10:59:36 | 105 | 0.51 | 0.29 | 0.67 | 0.03 | 0.08 | -0.17
2022-02-03 | 10:59:38 | 105 | 0.51 | 0.29 | 0.67 | 0.03 | 0.08 | -0.17
2022-02-03 | 10:59:40 | 105 | 0.51 | 0.29 | 0.67 | 0.03 | 0.08 | -0.17
2022-02-03 | 10:59:43 | 105 | 0.51 | 0.29 | 0.67 | 0.03 | 0.08 | -0.17
2022-02-03 | 10:59:45 | 105 | 0.51 | 0.29 | 0.67 | 0.03 | 0.08 | -0.17
2022-02-03 | 10:59:47 | 105 | 0.51 | 0.29 | 0.67 | 0.03 | 0.08 | -0.17
2022-02-03 | 10:59:49 | 105 | 0.51 | 0.29 | 0.67 | 0.03 | 0.08 | -0.17
2022-02-03 | 10:59:51 | 106 | 0.52 | 0.3 | 0.7 | 0.05 | 0.1 | -0.14
2022-02-03 | 10:59:53 | 105 | 0.51 | 0.29 | 0.67 | 0.03 | 0.08 | -0.17
2022-02-03 | 10:59:56 | 105 | 0.51 | 0.29 | 0.67 | 0.03 | 0.08 | -0.17
2022-02-03 | 10:59:58 | 105 | 0.51 | 0.29 | 0.67 | 0.03 | 0.08 | -0.17
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

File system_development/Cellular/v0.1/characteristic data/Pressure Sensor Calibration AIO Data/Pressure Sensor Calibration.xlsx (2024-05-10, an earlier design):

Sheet: Sheet1
depth-equivalent PSI | Voltage | Depth |  | Testing occurred at 1009.0mb atmospheric
6.852813853 | 3.12 | 15.83 |  | 3.079
6.493506494 | 2.98 | 15 |  | 2.923
6.060606061 | 2.81 | 14
5.627705628 | 2.64 | 13
5.194805195 | 2.48 | 12 |  |  |  | If you know your reading to 1/10th of a foot,
4.761904762 | 2.3 | 11
4.329004329 | 2.13 | 10
3.896103896 | 1.96 | 9
3.463203463 | 1.79 | 8
3.03030303 | 1.61 | 7
2.597402597 | 1.44 | 6
2.218614719 |  | 5.125 |  | 1.295 | 1720hrs
2.164502165 | 1.27 | 5 | 1721hrs |  |  | 5.1 | 27.205972
1.731601732 | 1.09 | 4 |  |  |  | 5 | 26.62769
1.298701299 | 0.91 | 3 |  |  |  | 4.9 | 26.049408
0.8658008658 | 0.74 | 2 |  |  |  | 4.8 | 25.471126
0.4329004329 | 0.56 | 1 |  |  |  | 4.7 | 24.892844
0 | 0.38 | 0 |  | 0.362 |  | 4.6 | 24.314562
 |  |  |  |  |  | 4.5 | 23.73628
 |  |  |  |  |  | 4.4 | 23.157998
0.1 |  | 0.231 |  |  |  | 4.3 | 22.579716
 |  |  |  |  |  | 4.2 | 22.001434
 |  |  |  |  |  | 4.1 | 21.423152
 |  |  |  |  |  | 4 | 20.84487
 |  |  |  |  |  | 3.9 | 20.266588
 |  |  |  |  |  | 3.8 | 19.688306
 |  |  |  |  |  | 3.7 | 19.110024
 |  |  |  |  |  | 3.6 | 18.531742
 |  |  |  |  |  | 3.5 | 17.95346
 |  |  |  |  |  | 3.4 | 17.375178
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

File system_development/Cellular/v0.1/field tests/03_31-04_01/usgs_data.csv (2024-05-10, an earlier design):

 |  | date | time |  |  | stage
USGS | 2169506 | 3/31/2022 | 9:00 | EDT | 1.01 | 168.01
USGS | 2169506 | 3/31/2022 | 9:15 | EDT | 1.01 | 168.01
USGS | 2169506 | 3/31/2022 | 9:30 | EDT | 1.01 | 168.01
USGS | 2169506 | 3/31/2022 | 9:45 | EDT | 1 | 168
USGS | 2169506 | 3/31/2022 | 10:00 | EDT | 1 | 168
USGS | 2169506 | 3/31/2022 | 10:15 | EDT | 1 | 168
USGS | 2169506 | 3/31/2022 | 10:30 | EDT | 1 | 168
USGS | 2169506 | 3/31/2022 | 10:45 | EDT | 1 | 168
USGS | 2169506 | 3/31/2022 | 11:00 | EDT | 1.01 | 168.01
USGS | 2169506 | 3/31/2022 | 11:15 | EDT | 1.04 | 168.04
USGS | 2169506 | 3/31/2022 | 11:30 | EDT | 1.1 | 168.1
USGS | 2169506 | 3/31/2022 | 11:45 | EDT | 1.18 | 168.18
USGS | 2169506 | 3/31/2022 | 12:00 | EDT | 1.3 | 168.3
USGS | 2169506 | 3/31/2022 | 12:15 | EDT | 1.41 | 168.41
USGS | 2169506 | 3/31/2022 | 12:30 | EDT | 1.71 | 168.71
USGS | 2169506 | 3/31/2022 | 12:45 | EDT | 1.72 | 168.72
USGS | 2169506 | 3/31/2022 | 13:00 | EDT | 1.66 | 168.66
USGS | 2169506 | 3/31/2022 | 13:15 | EDT | 1.6 | 168.6
USGS | 2169506 | 3/31/2022 | 13:30 | EDT | 1.57 | 168.57
USGS | 2169506 | 3/31/2022 | 13:45 | EDT | 1.61 | 168.61
USGS | 2169506 | 3/31/2022 | 14:00 | EDT | 1.7 | 168.7
USGS | 2169506 | 3/31/2022 | 14:15 | EDT | 1.79 | 168.79
USGS | 2169506 | 3/31/2022 | 14:30 | EDT | 1.81 | 168.81
USGS | 2169506 | 3/31/2022 | 14:45 | EDT | 1.76 | 168.76
USGS | 2169506 | 3/31/2022 | 15:00 | EDT | 1.76 | 168.76
USGS | 2169506 | 3/31/2022 | 15:15 | EDT | 1.68 | 168.68
USGS | 2169506 | 3/31/2022 | 15:30 | EDT | 1.57 | 168.57
USGS | 2169506 | 3/31/2022 | 15:45 | EDT | 1.47 | 168.47
USGS | 2169506 | 3/31/2022 | 16:00 | EDT | 1.38 | 168.38
USGS | 2169506 | 3/31/2022 | 16:15 | EDT | 1.31 | 168.31
USGS | 2169506 | 3/31/2022 | 16:30 | EDT | 1.26 | 168.26
USGS | 2169506 | 3/31/2022 | 16:45 | EDT | 1.21 | 168.21
USGS | 2169506 | 3/31/2022 | 17:00 | EDT | 1.18 | 168.18
USGS | 2169506 | 3/31/2022 | 17:15 | EDT | 1.15 | 168.15
USGS | 2169506 | 3/31/2022 | 17:30 | EDT | 1.12 | 168.12
USGS | 2169506 | 3/31/2022 | 17:45 | EDT | 1.1 | 168.1
USGS | 2169506 | 3/31/2022 | 18:00 | EDT | 1.08 | 168.08
USGS | 2169506 | 3/31/2022 | 18:15 | EDT | 1.07 | 168.07
USGS | 2169506 | 3/31/2022 | 18:30 | EDT | 1.05 | 168.05
USGS | 2169506 | 3/31/2022 | 18:45 | EDT | 1.04 | 168.04

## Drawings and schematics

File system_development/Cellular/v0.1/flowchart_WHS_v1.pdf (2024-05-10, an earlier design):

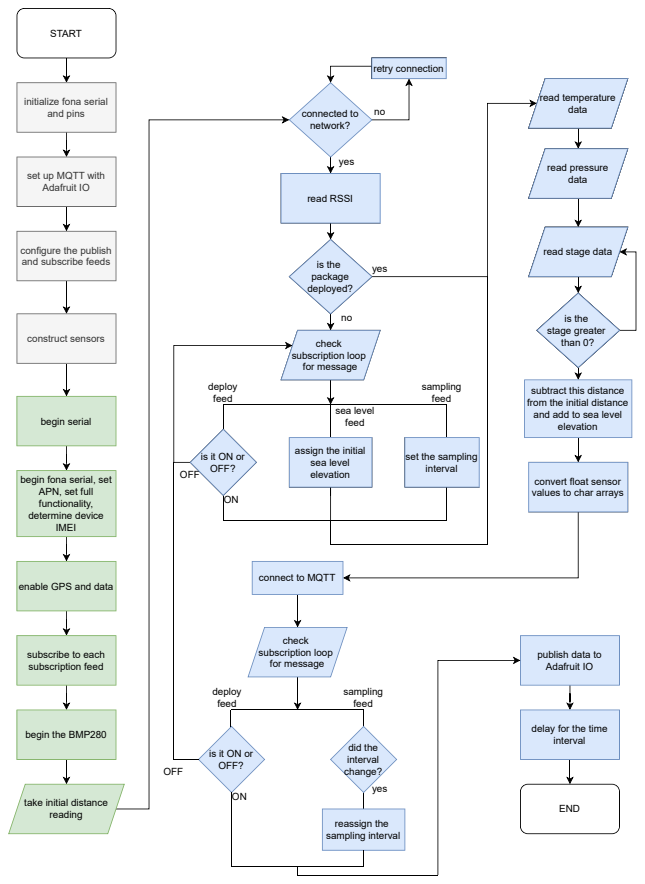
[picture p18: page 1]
START; construct sensors; begin serial; begin the BMP280; connected to network?; read RSSI; is the package deployed?; check subscription loop for message; read temperature data; deploy feed; sea level feed; yes; retry connection; read pressure data; is the stage greater than 0?; OFF? OFF; did the interval change?; sampling feed; reassign the sampling interval; END

initialize fona serial
and pins

set up MQTT with
Adafruit IO

configure the publish
and subscribe feeds

read stage data

subtract this distance
from the initial distance
and add to sea level
elevation

OFF?
OFF

assign the initial
sea level

set the sampling
interval

begin fona serial, set
APN, set full
functionality,
determine device
IMEI

convert float sensor
values to char arrays

connect to MQTT

enable GPS and data

subscribe to each
subscription feed

publish data to

delay for the time

take initial distance
reading

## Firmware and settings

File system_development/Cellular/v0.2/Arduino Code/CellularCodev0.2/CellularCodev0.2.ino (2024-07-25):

// Based on code from Timothy Woo (www.botletics.com)  /Github: https://github.com/botletics/SIM7000-LTE-Shield
//Also based on code from Adafruit - www.Adafruit.com
//Credit given to all creators of included libraries
//This project is open source
//Remote Cellular Water Height Sensor developed by Nicholas Liger, from previous work by Corrine Smith and Winford Janvrin
//in conjuction with ARTS - LAB at University of South and Carolina and South Carolina Department of Environmental Services (SC DES)

/************************* All Included Libraries - Do not change this section! *********************************/
//The below three libraries are special. See the Readme for more information.
#include "BotleticsSIM7000.h" // Botletics SIM7000 library developed by Timothy Woo
#include "Adafruit_MQTT.h" //Adafruit library for connection via MQTT to the Adafruit IO server
#include "Adafruit_MQTT_FONA.h" //Adafruit library for using cellular data to connect to Adafruit IO server. 
//The below two libraries work the SD reader as well as the SPI for communicating with the SD card reader
#include <SPI.h>  //SPI communication library
#include <SD.h> //SD card library
//The below libraries work the INA219 chip, RTC, and the I2C protocol for communicating with them
#include <Wire.h> //library for using I2C communication
#include <Adafruit_INA219.h> //Adafruit library for controlling INA219 voltage/current sensing chip
#include <DS3231.h> //library for RTC module
#include <LowPower.h> //library for using the sleep mode watchdog timer
#include "NewPing.h" //New Ping library for use with the sonar sensors

/************************* Botletics SIM7000 Set Up Section - Do not Edit! *********************************/
#define SIMCOM_7000 //from Botletics library, determine the model of SIM chip
// For botletics SIM7000 shield
#define BOTLETICS_PWRKEY 6
#define RST 7
//#define DTR 8 // Connect with solder jumper
//#define RI 9 // Need to enable via AT commands
#define TX 10 // Microcontroller RX
#define RX 11 // Microcontroller TX
//#define T_ALERT 12 // Connect with solder jumper

//Set up serial communication
#include <SoftwareSerial.h>
SoftwareSerial modemSS = SoftwareSerial(TX, RX);
SoftwareSerial *modemSerial = &modemSS;

// Use this one for LTE CAT-M/NB-IoT modules (like SIM7000)
// Notice how we don't include the reset pin because it's reserved for emergencies on the LTE module!
Adafruit_FONA_LTE modem = Adafruit_FONA_LTE();

/************************* Adafruit.io Setup - Enter your username and password for Adafruit IO here *********************************/
#define AIO_SERVER      "io.adafruit.com" //Adafruit IO server information
#define AIO_SERVERPORT  1883 //Adafruit IO server information
#define AIO_USERNAME    "" //Username of Adafruit account you are trying to connect with
#define AIO_KEY         "" //Key for Adafruit account you are trying to connect with

// Setup the FONA MQTT class by passing in the modem class and MQTT server and login details.
Adafruit_MQTT_FONA mqtt(&modem, AIO_SERVER, AIO_SERVERPORT, AIO_USERNAME, AIO_KEY);

// How many transmission failures in a row we're OK with before reset
uint8_t txfailures = 0;  

/****************************** Creating Feeds for the Adafruit IO***************************************/
// MQTT paths for Adafruit IO should follow the form: <username>/feeds/<feedname>
// After Publish/Subscribe, the name of the feed is saved as a variable for later use!
/******************************Feeds for the Adafruit IO***************************************/
//All Publish paths are for sending data from the Arduino to the Adafruit Server
Adafruit_MQTT_Publish sonar1 = Adafruit_MQTT_Publish(&mqtt, AIO_USERNAME "/feeds/sonar-sensor-1");
Adafruit_MQTT_Publish sonar2 = Adafruit_MQTT_Publish(&mqtt, AIO_USERNAME "/feeds/sonar-sensor-2");
Adafruit_MQTT_Publish batteryVoltage = Adafruit_MQTT_Publish(&mqtt, AIO_USERNAME "/feeds/battery-voltage");
Adafruit_MQTT_Publish internalTemperature = Adafruit_MQTT_Publish(&mqtt, AIO_USERNAME "/feeds/temperature");
Adafruit_MQTT_Publish signalStrength = Adafruit_MQTT_Publish(&mqtt, AIO_USERNAME "/feeds/signal-strength");
//All Subscribe paths are for sending data from the Adafruit server to the Arduino
Adafruit_MQTT_Subscribe initialHeight1 = Adafruit_MQTT_Subscribe(&mqtt, AIO_USERNAME "/feeds/initial-height-1");
Adafruit_MQTT_Subscribe initialHeight2 = Adafruit_MQTT_Subscribe(&mqtt, AIO_USERNAME "/feeds/initial-height-2");
/****************************** Declaring Other Variables ***************************************/
//random variables for running Botletics scripts, do not edit
uint8_t readline(char *buff, uint8_t maxbuff, uint16_t timeout = 0);
char imei[16] = {0}; // Use this for device ID
uint8_t type;

// Char/String variables for holding the variables
//for transmitting to Adafruit IO
char battBuff[12],dist1Buff[12],dist2Buff[12],tempBuff[12],signalBuff[12];

//Variables for setting up the INA219 power monitoring device
Adafruit_INA219 ina219; //declares the INA219 variable, do not edit
float busVoltage = 0; //the voltage reading on the battery input from INA219

//Variables for setting up the two ultrasonic sensors
const int trigPin1 = 47; //trigger pin for sonar sensor 1
const int echoPin1 = 46; //echo pin for sonar sensor 1
const int trigPin2 = 45; //trigger pin for sonar sensor 2
const int echoPin2 = 44; //echo pin for sonar sensor 2
const int maxDist = 600; // max distance in cm for sonar sensor, same for both
NewPing sonar_sensor_1(trigPin1, echoPin1, maxDist); //set up NewPing variable for sonar sensor 1
NewPing sonar_sensor_2(trigPin2, echoPin2, maxDist); //set up NewPing variable for sonar sensor 2
float distance1=0; //variable for distance measured by sonar sensor 1
float distance2=0; //variable for distance measured by sonar sensor 2
float initHght1 = 0; //Elevation of the ultrasonic sensor 1 at set up, used
//to calibrate the sensor readings (usually done in reference to sea level)
float initHght2 = 0; //Elevation of the ultrasonic sensor 1 at set up, used
//to calibrate the sensor readings (usually done in reference to sea level)
float height1 = 0; //Height variable for the current water height calculated from ultrasonic sensor 1
//(usually done with reference to sea level)
float height2 = 0; //Same for sensor 2

//Variables for setting up the SD card and RTC
char timeStamp[32]; //Char/string variable for holding time stamp
const int chipSelect = 53; //Chip Select for the SD card
char dayStampFileName[20]; //Char/string variable for holding the day stamp for naming
//file in SD card
DS3231 myRTC; //RTC variable for using DS3231 library scripts

//Variables governing the sampling rate of the sensor
uint8_t currentTime = 1; //variable used to hold "minute" reading of RTC
uint8_t lastTime = 1; //variable used to hold the previous "minute" reading of RTC
//See code later for more description of the above variables
int delayTime = 5; //time in minutes between between readings

#define MQTT_CONN_KEEPALIVE 300 //Adafruit IO defaults to 5 mins of connection
bool firstRun = true;

//*******************************Void Set up************************************
void setup() {
  Serial.begin(9600); //begin the Serial monitor
  Wire.begin(); //begin communication with I2C, needed for RTC module and INA219 chip

  //The below section activates the SD card
  Serial.print("Initializing SD card...");
  // see if the card is present and can be initialized:
  while (!SD.begin(chipSelect)) {
    Serial.println("Card failed, or not present. Retrying...");
    delay(2000);
  }
  Serial.println("card initialized.");

  //These following lines start up and calibrate the INA219 chip
  while (!ina219.begin()) { //these lines initialize the INA219 chip
    Serial.println("Failed to find INA219 chip...");
    delay(2000);
  }
  //To use a slightly lower 32V, 1A range (higher precision on amps):
  //ina219.setCalibration_32V_1A();
  //Or to use a lower 16V, 400mA range (higher precision on volts and amps):
  ina219.setCalibration_16V_400mA();

  //The below section powers on and sets up the SIM7000 chip so that the
  //package can connect to the cellular network
  pinMode(RST, OUTPUT);
  digitalWrite(RST, HIGH); // Default state
  //This function is declared below and powers on the Botletics shield
  BotleticsSetup();
  //These lines set up the ability to subscribe from the Adafruit IO Dashboard
  mqtt.subscribe(&initialHeight1);
  mqtt.subscribe(&initialHeight2);
  MQTT_connect(); //This connects our sensor package to the Adafruit IO
}

void loop() {
  Serial.println("The loop begins here!");
  //This if statement will not allow the program to proceed until the Initial Height for both ultrasonic sensors have been
  //entered from the Adafruit IO
  while (initHght1 == 0 || initHght2 == 0){
      // This is our 'wait for incoming subscription packets' busy subloop
    Adafruit_MQTT_Subscribe *subscription;
    while ((subscription = mqtt.readSubscription(5000))) {
      if (subscription == &initialHeight1) {
        Serial.print(F("*** Got: "));
        Serial.println((char *)initialHeight1.lastread);
        initHght1 = atof((char *)initialHeight1.lastread);
      }
      if (subscription == &initialHeight2) {
        Serial.print(F("*** Got: "));
        Serial.println((char *)initialHeight2.lastread);
        initHght2 = atof((char *)initialHeight2.lastread);
      }
    }
    Serial.println(initHght1);
    Serial.println(initHght2);
    Serial.println("You have not entered the initial heights yet!");
    delay(2000);
    }
  DateTime now = RTClib::now();; //creates the "now" variable from the RTC to save the timeStamp
  currentTime = now.minute(); //saves the current minute as a variable

  //This "if" loop contains all of the code to run the package on loop. The sampling rate set in the Adafruit Dashboard gives the
  //frequency this loop runs on. Every nth minute, this loop will transmit data to the Adafruit IO server
  if (currentTime %delayTime == 0 && currentTime != lastTime || firstRun == true){
    //We first run the MQTT connect function to make sure that our connection to the server is active! 
    //If not, then the SIM7000 shield will reboot. All details found in the Void MQTT connect section below
    MQTT_connect();
    //This section creates the timestamps from the RTC module
    sprintf(timeStamp, "%02d:%02d:%02d %02d/%02d/%02d", now.hour(), now.minute(), now.second(), now.day(), now.month(), now.year());  
    //the above line creates a timestamp that is used to date data saved to the SD card
    snprintf(dayStampFileName, 20, "%02d%02d%02d.txt", now.day(), now.month(), now.year());  
    //the above line creates a name for the SD card files so that a new file is created every new day
    Serial.print(F("Date/Time: ")); //uncomment to debug
    Serial.println(timeStamp);

    //This line retrieves temperature in Celcius from the RTC
    float rtcTemp = myRTC.getTemperature();
    float tempF = rtcTemp*(1.8)+32; //convert celcius to farenheit
    Serial.println(tempF);

    //This line gets the voltage of the battery from the INA219 chip
    busVoltage = ina219.getBusVoltage_V()+0.8; //get voltage from battery and add 0.8V to account for drop across diode
    Serial.println(busVoltage);

    //This section gets the current distance from the sonar sensors and calculates
    //the current height based on the elevation of sensor minus the distance
    // h = h0 - d, and converts the reading to ft
    distance1 = sonar_sensor_1.convert_in(sonar_sensor_1.ping_median(5)); //The median function gives the median value of five quick samples
    delay(1000); //This second delay keeps the sensors from interfering with each other
    distance2 = sonar_sensor_2.convert_in(sonar_sensor_2.ping_median(5)); //same as above for sensor 2
    height1 = initHght1 - (distance1)/(12); //convert from inches to feet
    height2 = initHght2 - (distance2)/(12);
    Serial.print("Height 1 is: "); //uncomment to debug
    Serial.print(height1);
    Serial.print("  Height 2 is: ");
    Serial.println(height2);

// This section saves the data to the SD card, before we attempt to transmit the data over the cell network
//Because the cell connection crashes frequently, we save the data to the SD card first so that we can have
//a more complete set of data for future investigation
    Serial.println(dayStampFileName);
    //This line creates a new file named with the day time stamp (DDMMYYYY)
    //or opens the file if this name already exists
    //The SD cards have a tendency to become corrupted which can ruin a long term test
    //if the data is all saved to a single file, so this method creates a new CSV for every day
    //so that even if a file is corrupted, we will still have the data from every other day
    if (SD.exists(dayStampFileName) == 0) {
      File dataFile = SD.open(dayStampFileName, FILE_WRITE);
      if (dataFile){
        dataFile.println("Ultrasonic 1 Height Reading (ft), Ultrasonic 2 Height Reading (ft), Battery Voltage (V), Internal Temperature (F), Timestamp");
        dataFile.close();
      }
      else {
      Serial.println("error opening datalog.txt");
      }
    }
    // The below section creates a new entry in SD card which records all the relevant
    // information and the timestamp in a CSV format
    File dataFile = SD.open(dayStampFileName, FILE_WRITE);
    if (dataFile) {
        dataFile.print(height1);
        dataFile.print(",");
        dataFile.print(height2);
        dataFile.print(",");
        dataFile.print(busVoltage);
        dataFile.print(",");
        dataFile.print(tempF);
        dataFile.print(",");
        dataFile.println(timeStamp);
        dataFile.close();
      }
    // if the file isn't open, pop up an error:
    else {
      Serial.println("error opening datalog.txt");
    }

    //This creates string variables from numbers for transmission to Adafruit IO
    dtostrf(height1, 1, 2, dist1Buff);
    dtostrf(height2, 1, 2, dist2Buff);
    dtostrf(busVoltage, 1, 2, battBuff);
    dtostrf(tempF, 1, 2, tempBuff);

    //This section gauges the signal strength of the cellular connection
    // Read the raw RSSI value
    uint8_t n = modem.getRSSI();
    Serial.print(n); Serial.println(F(" RSSI"));
    dtostrf(n, 1, 2, signalBuff); //This saves the signal strength in raw RSSI to a string for transmission

    //This section connects the device to Adafruit IO and publishes the variables
    // Ensure the connection to the MQTT server is alive (this will make the first
    // connection and automatically reconnect when disconnected). See the MQTT_connect
    // function definition further below.

    // Now publish all the data to different feeds!
    // The MQTT_publish_checkSuccess handles repetitive stuff.
    MQTT_publish_checkSuccess(sonar1, dist1Buff);
    MQTT_publish_checkSuccess(sonar2, dist2Buff);
    MQTT_publish_checkSuccess(batteryVoltage, battBuff);
    MQTT_publish_checkSuccess(internalTemperature, tempBuff);
    MQTT_publish_checkSuccess(signalStrength, signalBuff);
  // Delay until next post
    lastTime = currentTime; //This prevents the "if" loop from running again and again
    //in the same minute

    Serial.println("Going to sleep!");
    firstRun = false;
  } 
  //Between sampling times, the Arduino is sent into light sleep which helps to save on power
  //It wakes up every 4 seconds to check the time and goes back to sleep unless the sampling rate
  //conditions are met in the "if" loop
  else {
    LowPower.powerDown(SLEEP_8S, ADC_OFF, BOD_OFF);
     delay(5);
  }
}  

//Our custom code ends here. Everything below are premade function codes

//************************** Function Codes - Do not alter these! **************************
void BotleticsSetup() {
    //The following lines are for powering on and starting up 
  //the SIM7000 Botletics shield
  modem.powerOn(BOTLETICS_PWRKEY); // Power on the module
  moduleSetup(); // Establishes first-time serial comm and prints IMEI
  // Set modem to full functionality
  modem.setFunctionality(1); // AT+CFUN=1
  modem.setNetworkSettings(F("hologram")); // For Hologram SIM card
    #if !defined(SIMCOM_3G) && !defined(SIMCOM_7500) && !defined(SIMCOM_7600)
      // Disable data just to make sure it was actually off so that we can turn it on
      if (!modem.enableGPRS(false)) //Serial.println(F("Failed to disable data!"));
      // Turn on data
      while (!modem.enableGPRS(true)) {
        //Serial.println(F("Failed to enable data, retrying..."));
        delay(2000);
      }
      Serial.println(F("Enabled data!"));
    #endif
      
    //The following section connects the SIM card to the cellular network and enables data
    //so we can transmit to Adafruit IO
    // Connect to cell network and verify connection
    // If unsuccessful, keep retrying every 2s until a connection is made
    while (!netStatus()) {
      Serial.println(F("Failed to connect to cell network, retrying..."));
      delay(2000);
    }
    Serial.println(F("Connected to cell network!"));
    // Open wireless connection if not already activated
    if (!modem.wirelessConnStatus()) {
      while (!modem.openWirelessConnection(true)) {
        Serial.println(F("Failed to enable connection, retrying..."));
        delay(2000);    
      }
      Serial.println(F("Enabled data!"));
    }
    else {
      Serial.println(F("Data already enabled!"));
    }
    Serial.println(F("---------------------"));
}
//This function is what activates the SIM7000 card in the Botletics shield
void moduleSetup() {
  // SIM7000 takes about 3s to turn on and SIM7500 takes about 15s
  // Press Arduino reset button if the module is still turning on and the board doesn't find it.
  // When the module is on it should communicate right after pressing reset

  // Software serial:
  modemSS.begin(115200); // Default SIM7000 shield baud rate

  Serial.println(F("Configuring to 9600 baud"));
  modemSS.println("AT+IPR=9600"); // Set baud rate
  delay(100); // Short pause to let the command run
  modemSS.begin(9600);
  if (! modem.begin(modemSS)) {
    Serial.println(F("Couldn't find modem"));
    modem.powerDown();
    return;    
  }

  type = modem.type();
  Serial.println(F("Modem is OK"));
  Serial.print(F("Found "));
  switch (type) {
    case SIM800L:
      Serial.println(F("SIM800L")); break;
    case SIM800H:
      Serial.println(F("SIM800H")); break;
    case SIM808_V1:
      Serial.println(F("SIM808 (v1)")); break;
    case SIM808_V2:
      Serial.println(F("SIM808 (v2)")); break;
    case SIM5320A:
      Serial.println(F("SIM5320A (American)")); break;
    case SIM5320E:
      Serial.println(F("SIM5320E (European)")); break;
    case SIM7000:
      Serial.println(F("SIM7000")); break;
    case SIM7070:
      Serial.println(F("SIM7070")); break;
    case SIM7500:
      Serial.println(F("SIM7500")); break;
    case SIM7600:
      Serial.println(F("SIM7600")); break;
    default:
      Serial.println(F("???")); break;
  }
  
  // Print module IMEI number.
  uint8_t imeiLen = modem.getIMEI(imei);
  if (imeiLen > 0) {
    Serial.print("Module IMEI: "); Serial.println(imei);
  }
}

//This function determines if the SIM card is connected to a cellular network
bool netStatus() {
  int n = modem.getNetworkStatus();
  
  Serial.print(F("Network status ")); Serial.print(n); Serial.print(F(": "));
  if (n == 0) Serial.println(F("Not registered"));
  if (n == 1) Serial.println(F("Registered (home)"));
  if (n == 2) Serial.println(F("Not registered (searching)"));
  if (n == 3) Serial.println(F("Denied"));
  if (n == 4) Serial.println(F("Unknown"));
  if (n == 5) Serial.println(F("Registered roaming"));

  if (!(n == 1 || n == 5)) return false;
  else return true;
}

// Function to connect and reconnect as necessary to the MQTT server.
// Should be called in the loop function and it will take care if connecting.
void MQTT_connect() {
  int8_t ret;

  // Stop if already connected.
  if (mqtt.connected()) {
    return;
  }

  Serial.println("Connecting to MQTT... ");

  while ((ret = mqtt.connect()) != 0) { // connect will return 0 for connected
      modem.powerDown();
      delay(10000);
      BotleticsSetup();
  }
  Serial.println("MQTT Connected!");
}

//This function publishes data to the Adafruit IO server
void MQTT_publish_checkSuccess(Adafruit_MQTT_Publish &feed, const char *feedContent) {
  Serial.println(F("Sending data..."));
   if (!feed.publish(feedContent)) {
    Serial.println(F("Failed"));
  }
  else {
    Serial.println(F("OK!"));
    txfailures = 0;
  }
}

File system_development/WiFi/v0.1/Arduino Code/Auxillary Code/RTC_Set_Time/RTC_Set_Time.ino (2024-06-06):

#include <RTClib.h>
#include <Wire.h>
 
RTC_DS3231 rtc;
 
char t[32];
 
void setup() 
{
  Serial.begin(9600);
  Wire.begin();
 
  rtc.begin();
  rtc.adjust(DateTime(F(__DATE__),F(__TIME__)));
  //rtc.adjust(DateTime(2014, 1, 21, 3, 0, 0));
  
 
}
 
void loop()
{
  DateTime now = rtc.now();
 
  sprintf(t, "%02d:%02d:%02d %02d/%02d/%02d",  now.hour(), now.minute(), now.second(), now.day(), now.month(), now.year());  
  
  Serial.print(F("Date/Time: "));
  Serial.println(t);
 
  delay(1000);
}

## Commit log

2024-05-10 initial push
    [DHEC_HOBO_DATA.xlsx, Pressure Sensor Calibration.xlsx, adafruit_data.csv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]
2024-05-10 re-named variations
    [DHEC_HOBO_DATA.xlsx, Pressure Sensor Calibration.xlsx, adafruit_data.csv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]
2024-05-13 Added Schematics
    Added Datalogging and Power Board schematics from KiCad software
    [Data Collection _ Logging PCB.kicad_pcb, Data Collection _ Logging PCB.kicad_sch, Power PCB.kicad_pcb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]
2024-05-13 Added For Public Use Folder
    Created a folder for easier public use for SC DHEC and other agencies
    [Cellular Water Height Sensor Package Parts List.csv]
2024-05-14 Test CSV updating
    [Cellular Water Height Sensor Package Parts List.csv]
2024-05-14 Update Cellular Water Height Sensor Package Parts List.csv
    [Cellular Water Height Sensor Package Parts List.csv]
2024-05-14 Updated the Public Use Folder
    [Data Collection _ Logging PCB.kicad_pcb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]
2024-05-16 Updated PCB Files
    Updated Datalogging PCB to correct sizing mistakes
    [Data Collection _ Logging PCB.kicad_pcb, Data Collection _ Logging PCB.kicad_sch]
2024-05-16 Redid the current PCB Information
    [Data Collection _ Logging PCB.kicad_pcb]
2024-05-16 Added labels to datalogging board
    [Data Collection _ Logging PCB.kicad_pcb]
2024-05-29 Added Code
    [Cellular Water Height Sensor Package Parts List.csv, Data Collection _ Logging PCB.kicad_pcb, Power PCB.kicad_pcb]
2024-06-18 Redid Power PCB
    Needed to redo Power PCB for accurate parts sizes
    [Cellular Water Height Sensor Package Parts List.csv, Data Collection _ Logging PCB.kicad_sch, Power PCB.kicad_pcb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]
2024-06-20 ReadMe updates
    [Data Collection _ Logging PCB.kicad_pcb, Data Collection _ Logging PCB.kicad_sch]
2024-06-21 Redid Wifi0.1 section
    [Data Collection _ Logging PCB.kicad_pcb, Data Collection _ Logging PCB.kicad_sch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]
2024-06-21 Redid PCB's for Wifi Version
    [Data Collection _ Logging PCB.kicad_pcb, Data Collection _ Logging PCB.kicad_sch, Power PCB.kicad_pcb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]
2024-07-10 Code Redo
    Added temperature and signal strength to transmission, also created back ups in code to reboot if connection fails
    [AdafruitIO_MQTT_Demo.ino, AdvanceAlarm.ino, AlarmInterrupt.ino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]
2024-07-12 PCB Edit/I2C code
    Changed the datalogging pcb to have a different 3.3V regulator and added an I2C address finding Arduino code for use with the INA219 chip
    [Cellular Water Height Sensor Package Parts List.csv, Data Collection _ Logging PCB.kicad_pcb, Data Collection _ Logging PCB.kicad_sch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]
2024-07-15 PCB updates
    Updated Power PCB so that INA219 chip is connected to ground and has a stable I2C address. Updated datalogging board with a bigger 3.3V regulator since the previous tiny one was not working in the board.
    [Power PCB.kicad_pcb, Power PCB.kicad_sch]
2024-07-20 Updated Intro Page
    Added updated photos to intro page to show the new design of the sensor package.
2024-07-20 Updated Instructions for assembly
2024-07-20 Updated assembly instructions
    updated assembly instructions.
2024-07-24 Update
    Updated ultrasonic sensor ordering in parts list.
    Updated photo of Lake Wallace Installation with labels.
    Updated Arduino code with 600 cm max distance for ultrasonic sensors.
    [Cellular Water Height Sensor Package Parts List.csv]
2024-07-25 Updated Wifi Code
    Updated Wifi code to reflect some of the changes made to the cellular code, order of operations, failsafes.
    [Cellular Water Height Sensor Package Parts List.csv, Data Collection _ Logging PCB.kicad_pcb, Data Collection _ Logging PCB.kicad_sch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]
2024-09-26 Redid Wifi Code
    Added some protection in the Wifi code to stop sonar sensor misreads and to prevent the Arduino from bricking whenever the device cannot connect to the Internet
    [WifiCode_v0.1.ino]
